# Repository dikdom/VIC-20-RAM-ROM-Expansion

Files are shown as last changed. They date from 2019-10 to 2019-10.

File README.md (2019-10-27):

# VIC-20-RAM-ROM-Expansion
Commodore VIC-20 RAM and ROM expansion module

This is a low cost memory expansion module for the Commodore VIC-20 machine. The module is capable of expanding the RAM1, RAM2, RAM3 and BLK1, BLK2, BLK3 and BLK5 memory areas. Altogether 35kB of RAM expansion, manually switchable way.

The module can host an AT28C256 32kB EEPROM chip also, containing 4x 8kB of ROM image mapped to BLK5. BLK5 is selectable: it can be either RAM (has to be enabled on the DIP switch) or can be ROM (DIP switch doesn't play any role).

BOM:
- 10k, 9+1 resistor bridge, SIL10
- 10k, 3# normal resistor
- 3pcs of 100nF, 1# ceramic capacitor (at least 5V, 50V is just fine)
- 22uF, 1# electrolythic capacitor (at lest 5V, 16V/25V is just fine),
- DIP switch, with 10 switches (3#)
- 74LS148, DIP-16 (+ optionally socket)
- 628128 RAM, 128kB, DIP-32 (+ optionally socket)
- 3 pin header + jumper

OPTIONAL
- AT28C256, 32kB EEPROM. Each 8kB bank shall contain an 8kB VIC20 cartridge program which is mapped to $A000-$BFFF (Block 5)
- Tactile push button for RESET

# Usage
The jumper can select what shall the VIC20 see on BLK5: ROM or RAM. If not used, then BLK5 will be unpopulated in VIC20. 
The DIP swithches 1-3 can turn on/off the RAM1/RAM2/RAM3 expansion (1kB each). The DIP switches 4-7 can turn on/off the BLK1,BLK2,BLK3,BLK5 RAM expansions (8kB each).
In case ROM is selected with the jumper, then DIP switches 9-10 can select the 8kB ROM bank from the EEPROM.
The DIP switch 8 is not used. 

# Directories
- eagle

  The Eagle design files (schematics and board plans and necessary libraries)

- doc

  Schematics, board in visible form (pdf) and the gerber file package.

# License #

Creative Commons License

This work is licensed under [Creative Commons Attribution-NonCommercial-ShareAlike 4.0 International License](https://creativecommons.org/licenses/by-nc-sa/4.0/).

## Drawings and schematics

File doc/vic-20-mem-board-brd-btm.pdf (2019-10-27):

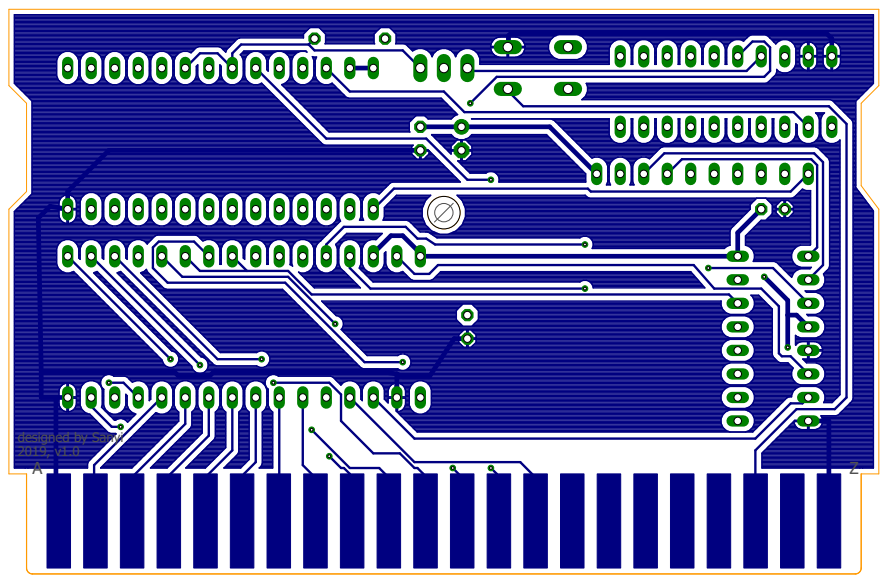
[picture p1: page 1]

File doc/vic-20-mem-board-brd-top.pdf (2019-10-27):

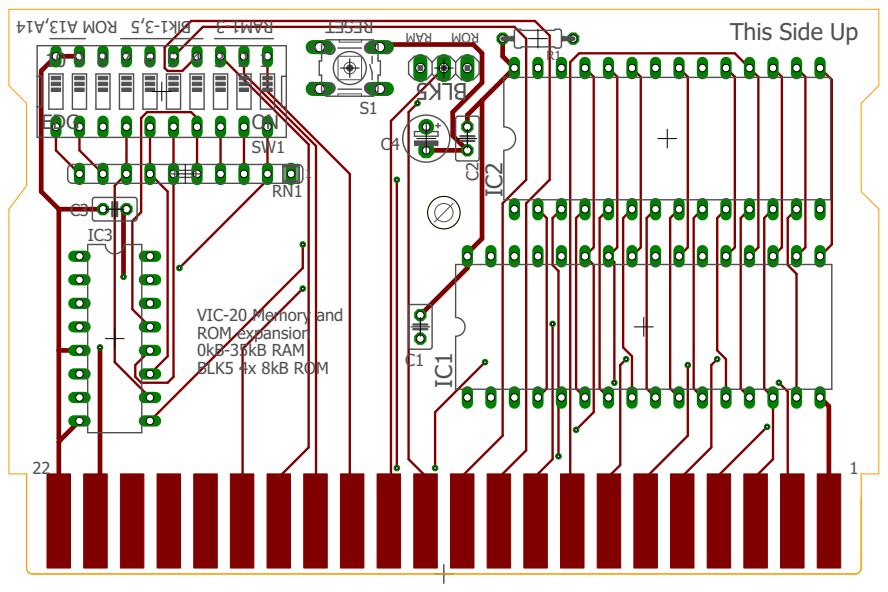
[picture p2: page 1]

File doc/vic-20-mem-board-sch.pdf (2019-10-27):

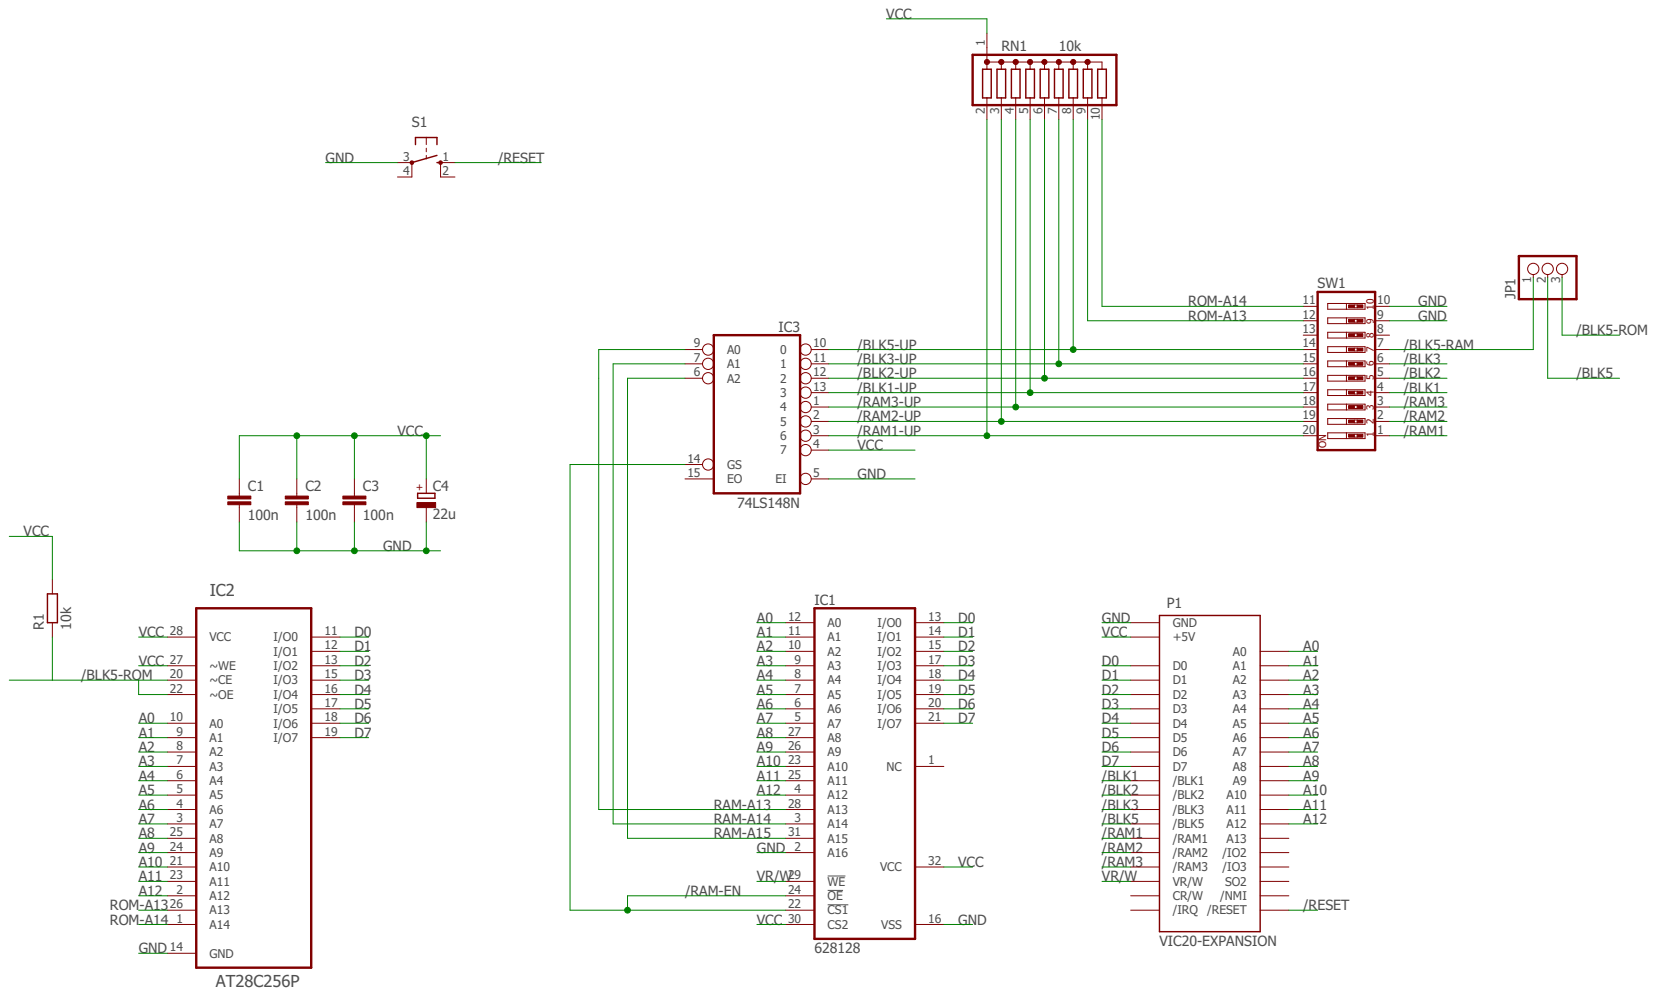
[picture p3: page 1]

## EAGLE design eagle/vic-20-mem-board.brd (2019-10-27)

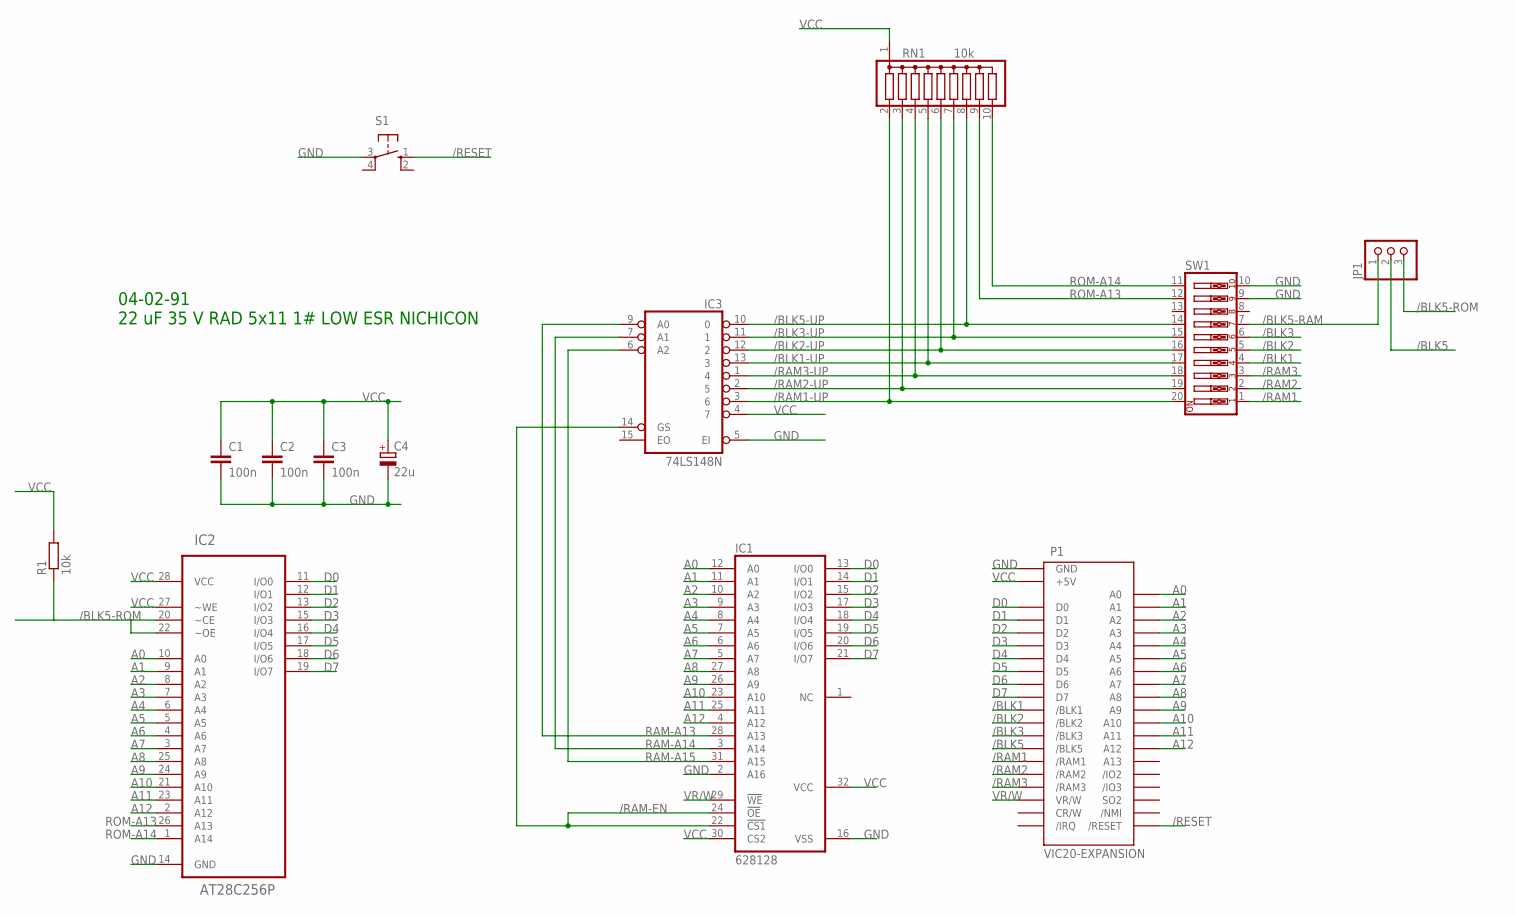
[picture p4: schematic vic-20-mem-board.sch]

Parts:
C1, C2, C3: 100n; C025-025X050
C4: 22u; E2,5-5
IC1: 628128; DIL32
IC2: AT28C256P; DIL28-6
IC3: 74LS148N; DIL16
JP1: PINHD-1X3; 1X03
P1: VIC20-EXPANSION; 44PINEDGE
R1: 10k; 0204/7
RN1: 10k; SIL10
S1: 10-XX; B3F-10XX
SW1: SW_DIP-10; EDG-10

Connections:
/BLK1: P1.10 (/BLK1), SW1.4
/BLK1-UP: IC3.13 (3), RN1.5, SW1.17
/BLK2: P1.11 (/BLK2), SW1.5
/BLK2-UP: IC3.12 (2), RN1.6, SW1.16
/BLK3: P1.12 (/BLK3), SW1.6
/BLK3-UP: IC3.11 (1), RN1.7, SW1.15
/BLK5: JP1.2, P1.13 (/BLK5)
/BLK5-RAM: JP1.1, SW1.7
/BLK5-ROM: IC2.20 (~CE), IC2.22 (~OE), JP1.3, R1.1
/BLK5-UP: IC3.10 (0), RN1.8, SW1.14
/RAM1: P1.14 (/RAM1), SW1.1
/RAM1-UP: IC3.3 (6), RN1.2, SW1.20
/RAM2: P1.15 (/RAM2), SW1.2
/RAM2-UP: IC3.2 (5), RN1.3, SW1.19
/RAM3: P1.16 (/RAM3), SW1.3
/RAM3-UP: IC3.1 (4), RN1.4, SW1.18
/RAM-EN: IC1.22 (!CS1), IC1.24 (!OE), IC3.14 (GS)
/RESET: P1.X (/RESET), S1.1 (S)
A0: IC1.12 (A0), IC2.10 (A0), P1.B (A0)
A1: IC1.11 (A1), IC2.9 (A1), P1.C (A1)
A2: IC1.10 (A2), IC2.8 (A2), P1.D (A2)
A3: IC1.9 (A3), IC2.7 (A3), P1.E (A3)
A4: IC1.8 (A4), IC2.6 (A4), P1.F (A4)
A5: IC1.7 (A5), IC2.5 (A5), P1.H (A5)
A6: IC1.6 (A6), IC2.4 (A6), P1.J (A6)
A7: IC1.5 (A7), IC2.3 (A7), P1.K (A7)
A8: IC1.27 (A8), IC2.25 (A8), P1.L (A8)
A9: IC1.26 (A9), IC2.24 (A9), P1.M (A9)
A10: IC1.23 (A10), IC2.21 (A10), P1.N (A10)
A11: IC1.25 (A11), IC2.23 (A11), P1.P (A11)
A12: IC1.4 (A12), IC2.2 (A12), P1.R (A12)
D0: IC1.13 (I/O0), IC2.11 (I/O0), P1.2 (D0)
D1: IC1.14 (I/O1), IC2.12 (I/O1), P1.3 (D1)
D2: IC1.15 (I/O2), IC2.13 (I/O2), P1.4 (D2)
D3: IC1.17 (I/O3), IC2.15 (I/O3), P1.5 (D3)
D4: IC1.18 (I/O4), IC2.16 (I/O4), P1.6 (D4)
D5: IC1.19 (I/O5), IC2.17 (I/O5), P1.7 (D5)
D6: IC1.20 (I/O6), IC2.18 (I/O6), P1.8 (D6)
D7: IC1.21 (I/O7), IC2.19 (I/O7), P1.9 (D7)
GND: C1.2, C2.2, C3.2, C4.-, IC1.2 (A16), IC1.16 (VSS), IC2.14 (GND), IC3.5 (EI), IC3.8 (GND), P1.1 (GND), P1.22 (GND), P1.A (GND), P1.Z (GND), S1.3, SW1.9, SW1.10
RAM-A13: IC1.28 (A13), IC3.9 (A0)
RAM-A14: IC1.3 (A14), IC3.7 (A1)
RAM-A15: IC1.31 (A15), IC3.6 (A2)
ROM-A13: IC2.26 (A13), RN1.9, SW1.12
ROM-A14: IC2.1 (A14), RN1.10, SW1.11
VCC: C1.1, C2.1, C3.1, C4.+, IC1.30 (CS2), IC1.32 (VCC), IC2.27 (~WE), IC2.28 (VCC), IC3.4 (7), IC3.16 (VCC), P1.21 (+5V), R1.2, RN1.1
VR/W: IC1.29 (!WE), P1.17 (VR/W)

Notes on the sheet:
04-02-91 22 uF 35 V RAD 5x11 1# LOW ESR NICHICON

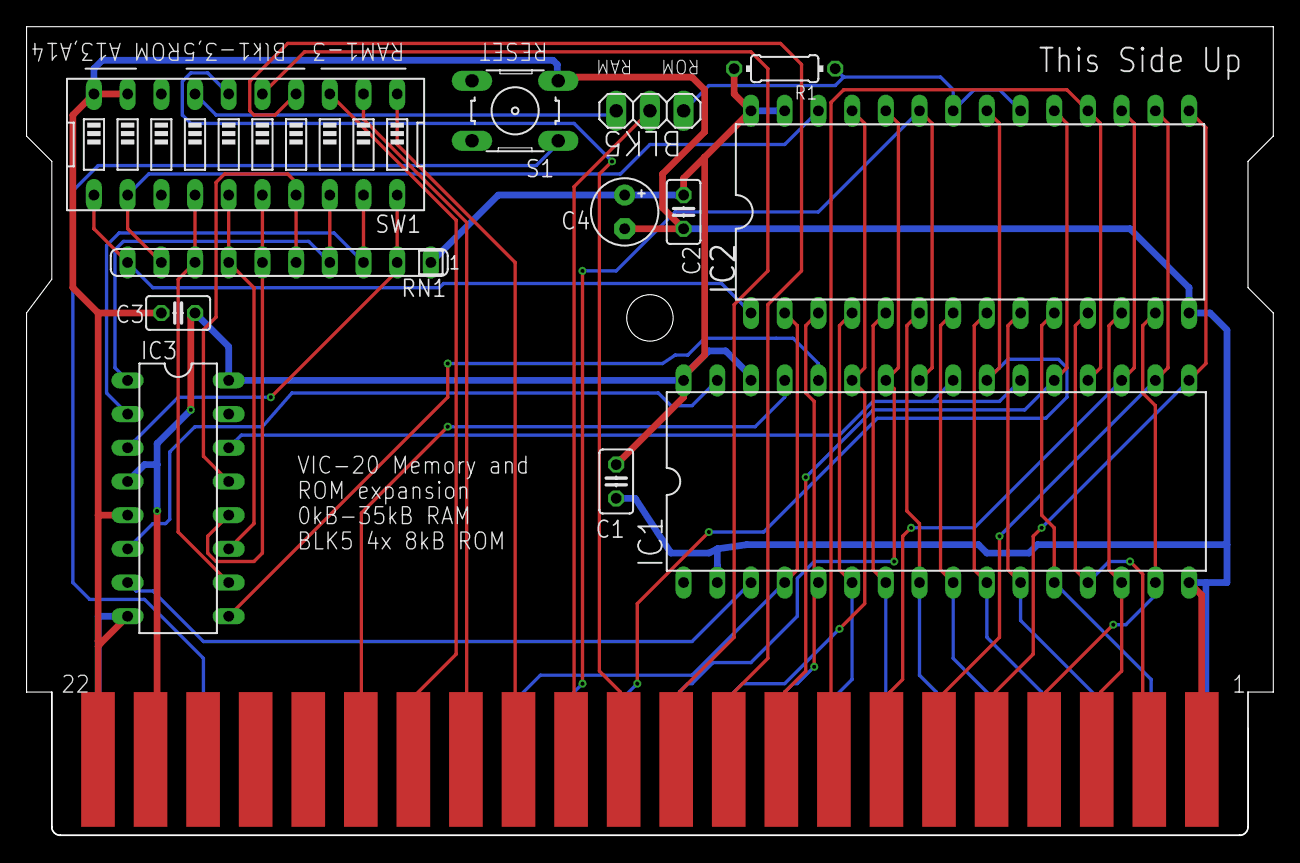
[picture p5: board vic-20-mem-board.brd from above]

Board: 2 copper layers, 94.0 x 61.0 mm, 13 parts (0 on the bottom side), 47 nets.

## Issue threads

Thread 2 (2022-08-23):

Possible to load one 8K image into $6000, and another into $A000?

VonHirsch, 2022-08-23:
Hello, I'm trying to simulate a game cartridge that has two 8K ROM images - one to load at $6000, and another into $A000.  Would this be possible using the jumpers on this board?

I'm not sure on the addresses of RAM1, RAM2, RAM3 and BLK1, BLK2, BLK3 and BLK5 memory areas.  Do they correspond to the ones below?  Which is $6000 and which $A000?

Thanks for this project!

$0000 System RAM (1K)
$0400 Empty space for 3K memory expansion
$1000 BASIC RAM (3.5K)
$1E00 Screen matrix (0.5K)
$2000 Empty space for first block of 8K memory expansion
$4000 Empty space for second block of 8K memory expansion
$6000 Empty space for third block of 8K memory expansion
$8000 Character ROM (4K)
$9000 I/O space for VIC chip, VIAs etc (4K space of which only parts are used)
$A000 RAM/ROM cartridge space, 8K
$C000 BASIC ROM (8K)
$E000 KERNAL ROM (8K)

dikdom, 2022-09-25:
Hi,
in short: no.
A bit longer: unfortunately no, but you have all the source files so you can customize it for your needs! :) When I designed this cart my aim was a simple cart that can provide a possibility to load a cart image (most of the carts are to be mapped to A000/BLK5) and keep the costs (bom and time to create) low.

RAM1,2 and 3 are small RAM areas (1kB each) under $1000 - starting at $0400.
BLK1, 2 and 3 are 8kB RAM areas starting at $2000, $4000 and $6000.
BLK5 is special. It can be selected on this card if there should be RAM or ROM area visible by VIC-20. In case ROM is selected then the last 2 switch selects which 8kB bank shall be mapped there from the ROM IC. In case if RAM is selected then you may have a full 35kB free RAM on you VIC-20 (but no cart).

I'm sure there are possibilities to do what you require just that needs a bit more logic put on that card:
- you need to enable the ROM on BLK5 _and_ BLK3 (instead of the current BLK5-ROM)
- you need to route BLK3 to the ROM as A13 (8kB)
- and of course you need to disable RAM access on BLK3 and BLK5
But this is something I would let YOU to do.. :)

(sorry for the late reply)

VonHirsch, 2022-09-25:
Thanks and no problem.  I ended up using some PCB's from here for the project:
http://sleepingelephant.com/~sleeping/ipw-web/bulletin/bb/viewtopic.php?f=11&t=8724
